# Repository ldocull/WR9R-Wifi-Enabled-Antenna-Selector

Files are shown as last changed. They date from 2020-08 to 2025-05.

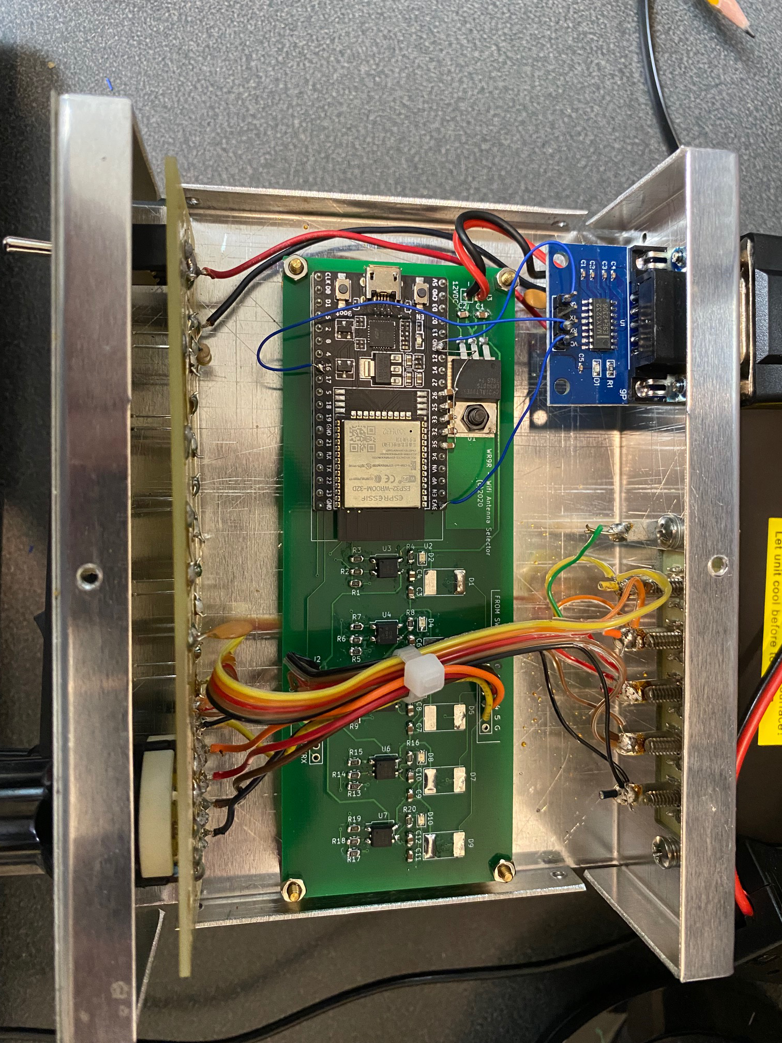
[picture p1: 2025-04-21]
RS232_Upgrade/Installed.jpg

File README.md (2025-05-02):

# WR9R-Wifi-Enabled-Antenna-Selector
This PCBA provides a method to remotely control antenna selection within a LAN using a standard browser.  I like to operate my HAM station, which is located in the basement, from other areas in or around my home.  This PCB and Firmware upgrade was easy to apply to my existing [Ameritron RCS-8V](https://mfjenterprises.com/products/rcs-8v) Antenna Selector control box while still maintaining manual control when I am in the basement radio-shack. 

## Key features:

- Directly fits within the existing enclosure
- Supports original manual control but adds remote control 
  (Changing the antenna choice at the front panel at any time, resets the device to the manual selection mode)
- Browser buttons can be named through the browser to support antenna upgrades

Typical Antenna Remote Controller Box

Installation

## Assembly Installation:

 The control wires were clipped from the back terminal strip and landed to the rear of the PCBA as shown above.
- New wires were the placed from the "To Relays" header to the terminal strip
- 12VDC power was picked up at the DC jack on the rear of the enclosure -- but could be picked up after the from panel switch on the front PCBA.

Main Operating Screen

## Setup:

 The software can be modified and hard coded to your network. Otherwise you can set it up using a phone or other internet-ready device. Connect to the Wifi hotspot generated by the Antenna Selector interface that looks like:  *WR9RasNNN*,  where *NNN* is a somewhat random number.
- Password is '*12345678*'
- On the same device, use a browser to then go to the host address:  https://192.168.4.1/SSID



- There, enter the SSID and Password for the network you wish to use within your LAN
- If you're plugged into the wifi module of the new PCBA with a USB cable, you can use a terminal session to see the new IP.  Otherwise. you will need to log into your router to find the new address assigned to the device.

## Antenna Names:
The buttons on the main screen can be renamed at any time. Just go to **htpps://*yourIPadd*/NAMES**



73
-[WR9R](http://wr9r.com/) 

___
Let us know that this work has been helpful to you.  Any proceeds will be used to offset expenses and further the art. 


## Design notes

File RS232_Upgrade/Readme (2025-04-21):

This upgrade allows the antenna selector to also directly monitor the K3.. allows for better responsiveness 
with band changes (does not have to rely on wifi). So, when running stuff like VarAC, no additional apps are requred for
monitoring and controlling the switch wirelessly. (Set the manual switch to position 5 to enable this function. 
Otherwise, everything is the same.)

73,
WR9R

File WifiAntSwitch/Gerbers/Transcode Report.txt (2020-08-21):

   ---- Transcoding 'C:\Users\LOCull.STRYKERCORP\Dropbox\KiCAD\WifiAntSwitch\Gerbers\WifiAntSwitch-Edge_Cuts.gbr' ----   Fri Aug 07 08:57:12 2020

D10   --> D100
-----------------------------------------------------------------

   ---- Transcoding 'C:\Users\LOCull.STRYKERCORP\Dropbox\KiCAD\WifiAntSwitch\Gerbers\WifiAntSwitch-F_Cu.gbr' ----   Fri Aug 07 08:57:12 2020

D17   --> D101
D18   --> D102
-----------------------------------------------------------------

   ---- Transcoding 'C:\Users\LOCull.STRYKERCORP\Dropbox\KiCAD\WifiAntSwitch\Gerbers\WifiAntSwitch-F_SilkS.gbr' ----   Fri Aug 07 08:57:12 2020

D10   --> D103
D11   --> D104
D12   --> D105
D13   --> D106
-----------------------------------------------------------------

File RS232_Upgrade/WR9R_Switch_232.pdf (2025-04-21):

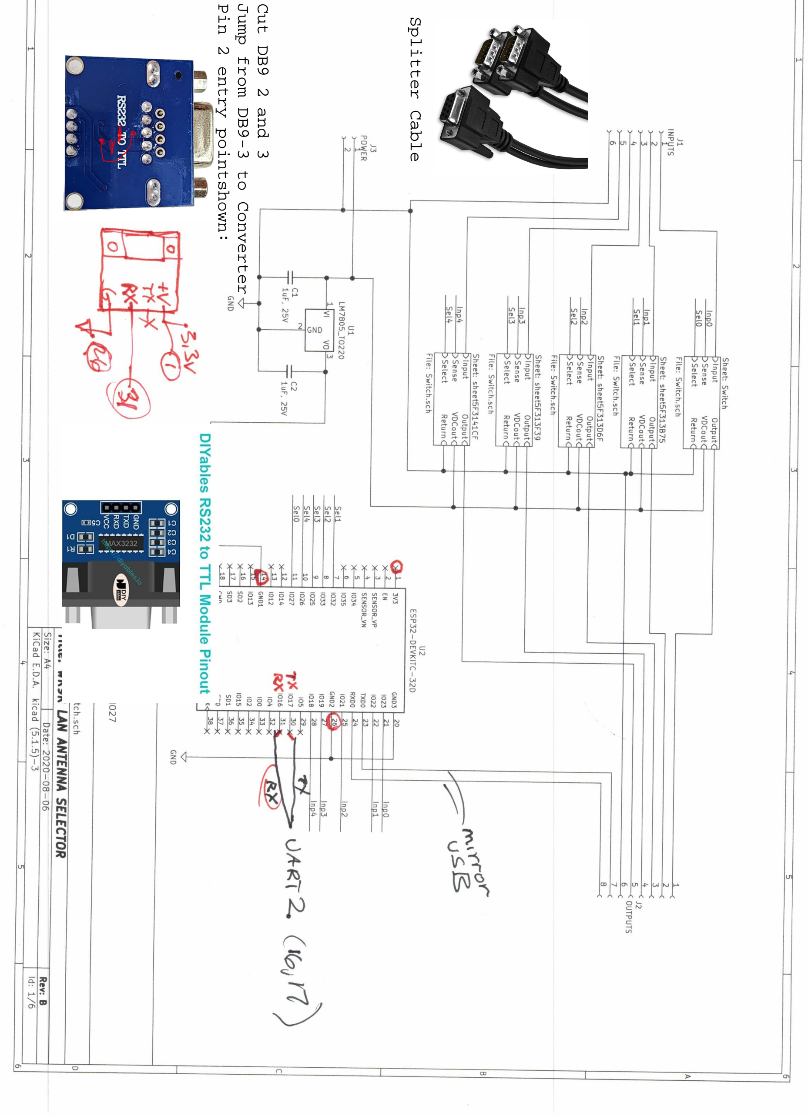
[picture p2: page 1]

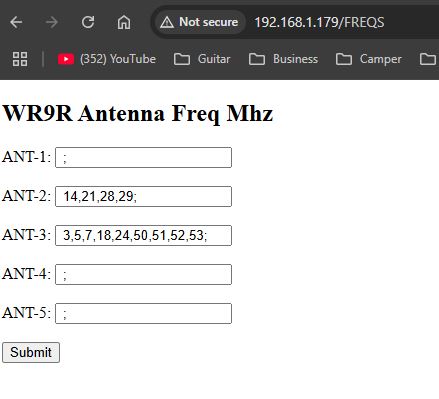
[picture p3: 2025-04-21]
RS232_Upgrade/FREQS_page_image.JPG

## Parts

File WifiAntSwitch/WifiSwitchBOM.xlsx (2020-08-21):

Id | Designator | Package | Quantity | Designation | Supplier and ref | Column1 | _1
1 | U2 | MODULE_ESP32-DEVKITC-32D | 1 | ESP32-DEVKITC-32D | 356-ESP32-DEVKITC32D (https://www.mouser.com/ProductDetail/356-ESP32-DEVKITC32D)
4 | U1 | TO-220-3_Horizontal_TabDown | 1 | LM7805_TO220 | LM7805CT/NOPB (https://www.mouser.com/ProductDetail/Texas-Instruments/LM7805CT-NOPB?qs=OYMYEaN9QmBS2GvaX6GSkQ%3D%3D)
5 | D9,D7,D5,D3,D1 | D_3220_8050Metric | 5 | RS07D-HM3-08 | RS07D-HM3-08
6 | U7,U6,U5,U4,U3 | SO-4_4.4x4.3mm_P2.54mm | 5 | ASSR-1218 | ASSR-1218-003E (https://www.mouser.com/ProductDetail/Broadcom-Avago/ASSR-1218-003E?qs=qH0Js2SSo34eOC1tecF2yQ%3D%3D)
7 | R20,R18,R16,R14,R12,R10,R8,R6,R4,R2 | R_0805_2012Metric | 10 | 6.8K | CR0805-FX-6801ELF (https://www.mouser.com/ProductDetail/Bourns/CR0805-FX-6801ELF)
8 | R19,R15,R11,R7,R3 | R_0805_2012Metric | 5 | 510 | CR0805-FX-5100ELF
9 | R17,R13,R9,R5,R1 | R_0805_2012Metric | 5 | 22K | CR0805-FX-2202ELF
12 | D10,D8,D6,D4,D2 | LED_0805_2012Metric | 5 | 599-0120-007F | 599-0120-007F (https://www.mouser.com/ProductDetail/Dialight/599-0120-007F?qs=gTYE2QTfZfSQtH19g4L1Mg%3D%3D)
13 | C12,C10,C8,C6,C4 | C_0805_2012Metric | 5 | 0.01uf, 100V | HMF212B7103KGHT (https://www.mouser.com/ProductDetail/Taiyo-Yuden/HMF212B7103KGHT)
14 | C11,C9,C7,C5,C3,C2,C1 | C_0805_2012Metric | 7 | 1uF, 25V | 08053G105MAT2A (https://www.mouser.com/ProductDetail/AVX/08053G105MAT2A)

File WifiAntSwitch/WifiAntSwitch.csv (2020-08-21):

Id | Designator | Package | Quantity | Designation | Supplier and ref
1 | U2 | MODULE_ESP32-DEVKITC-32D | 1 | ESP32-DEVKITC-32D
2 | J3 | PinHeader_1x02_P2.54mm_Vertical | 1 | POWER
3 | REF**,REF**,REF**,REF** | MountingHole_3mm | 4 | MountingHole_3mm
4 | U1 | TO-220-3_Horizontal_TabDown | 1 | LM7805_TO220
5 | D9,D7,D5,D3,D1 | D_3220_8050Metric | 5 | RS07D-HM3-08
6 | U7,U6,U5,U4,U3 | SO-4_4.4x4.3mm_P2.54mm | 5 | ASSR-1218
7 | R20,R18,R16,R14,R12,R10,R8,R6,R4,R2 | R_0805_2012Metric | 10 | 6.8K
8 | R19,R15,R11,R7,R3 | R_0805_2012Metric | 5 | 510
9 | R17,R13,R9,R5,R1 | R_0805_2012Metric | 5 | 22K
10 | J2 | PinHeader_1x08_P2.54mm_Vertical | 1 | OUTPUTS
11 | J1 | PinHeader_1x06_P2.54mm_Vertical | 1 | INPUTS
12 | D10,D8,D6,D4,D2 | LED_0805_2012Metric | 5 | 599-0120-007F
13 | C12,C10,C8,C6,C4 | C_0805_2012Metric | 5 | 0.01uf, 100V
14 | C11,C9,C7,C5,C3,C2,C1 | C_0805_2012Metric | 7 | 1uF, 25V

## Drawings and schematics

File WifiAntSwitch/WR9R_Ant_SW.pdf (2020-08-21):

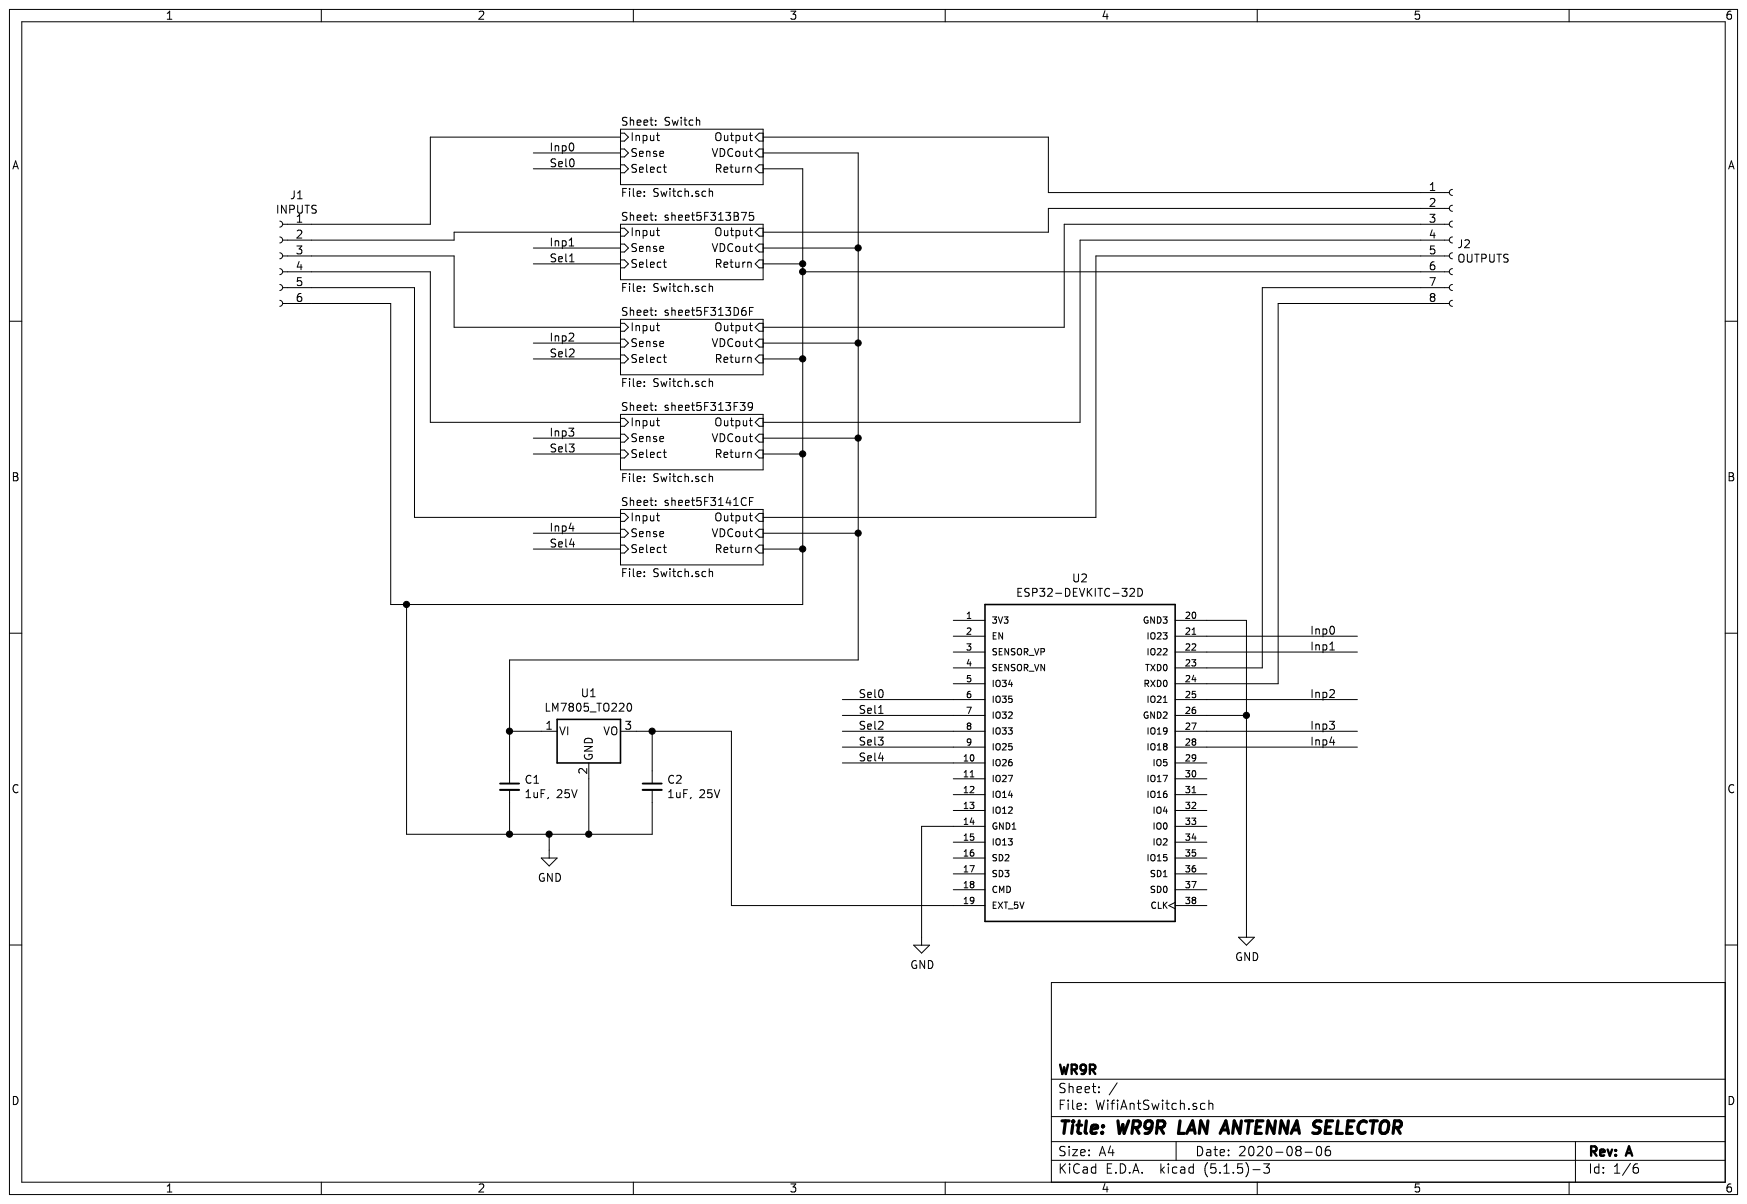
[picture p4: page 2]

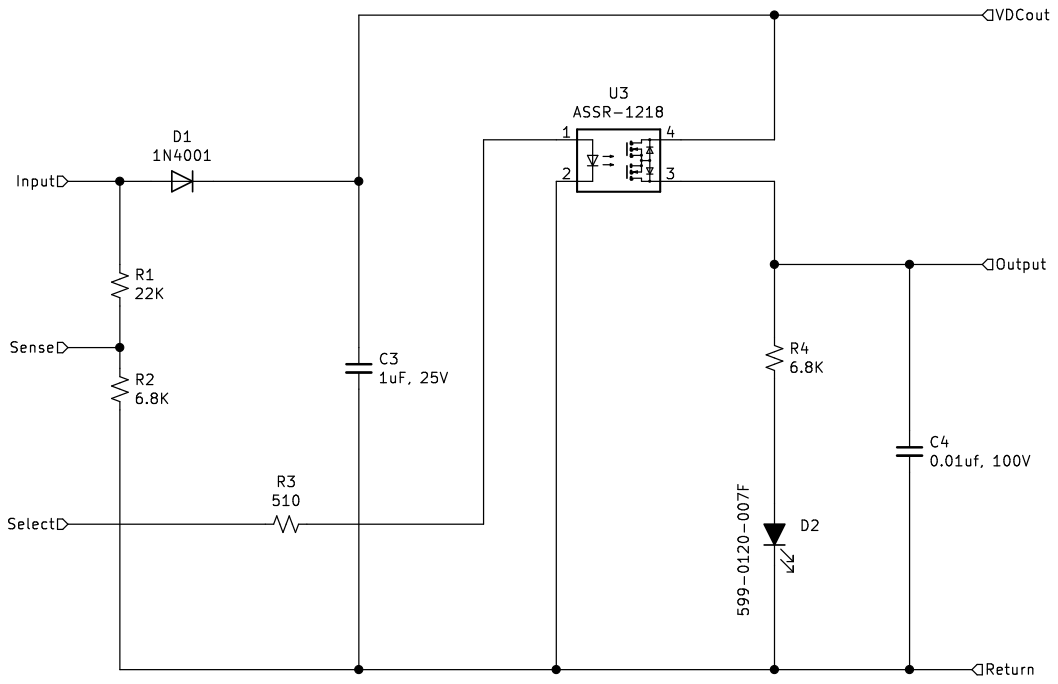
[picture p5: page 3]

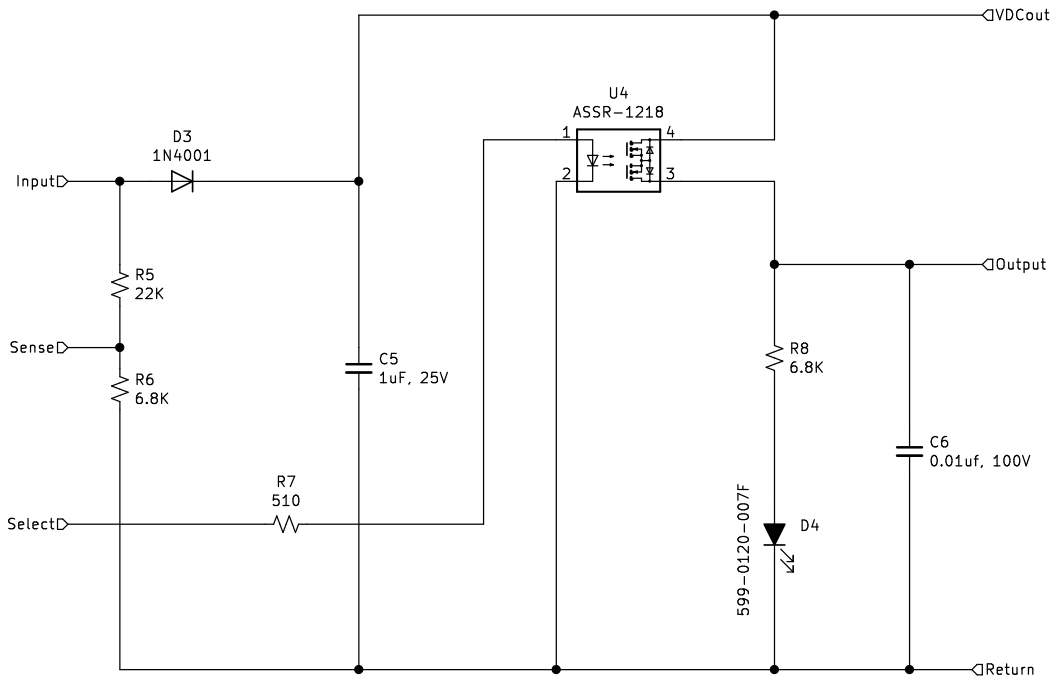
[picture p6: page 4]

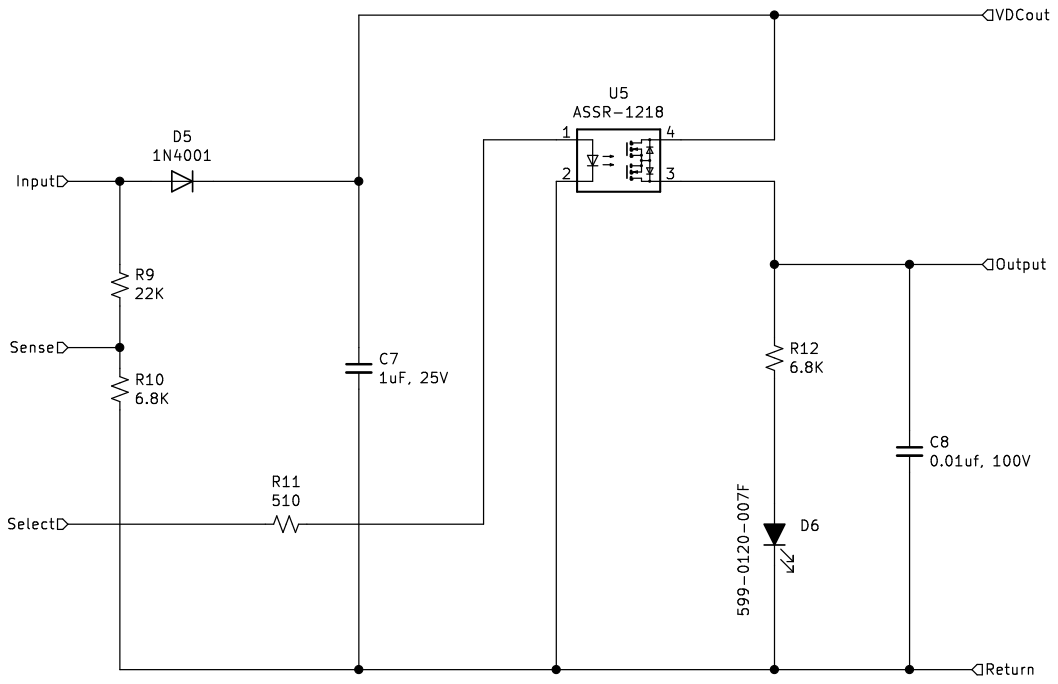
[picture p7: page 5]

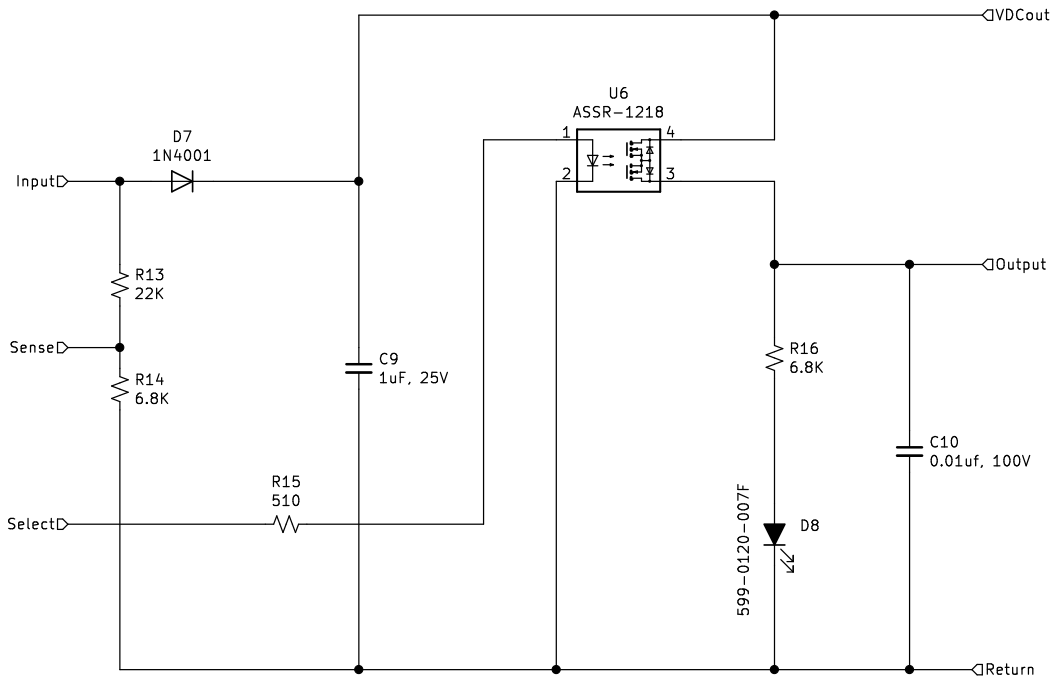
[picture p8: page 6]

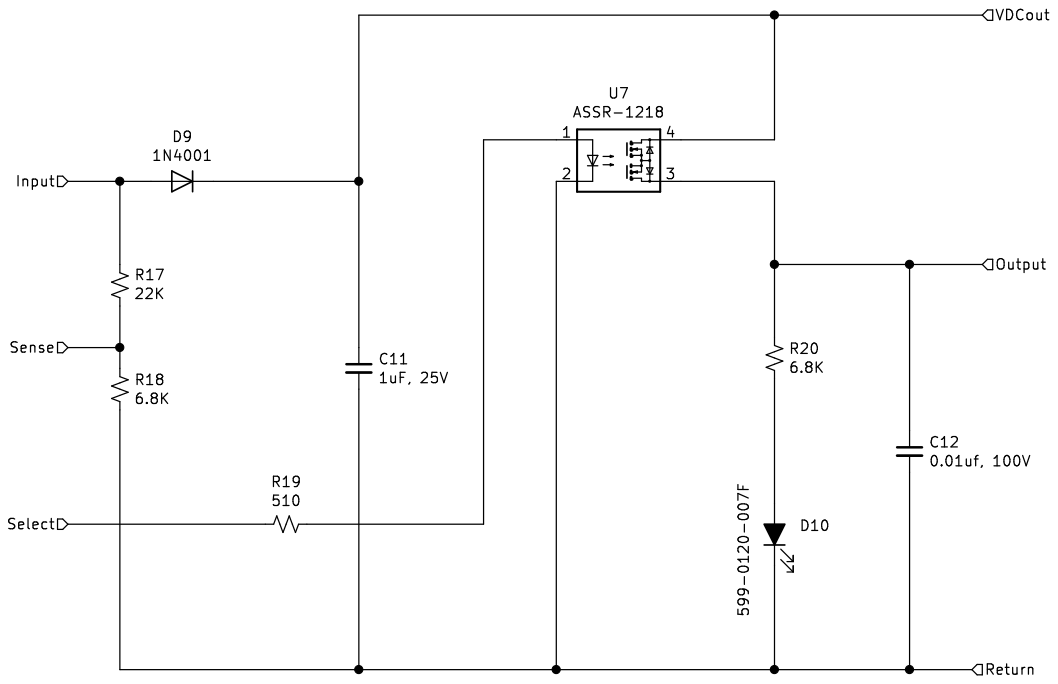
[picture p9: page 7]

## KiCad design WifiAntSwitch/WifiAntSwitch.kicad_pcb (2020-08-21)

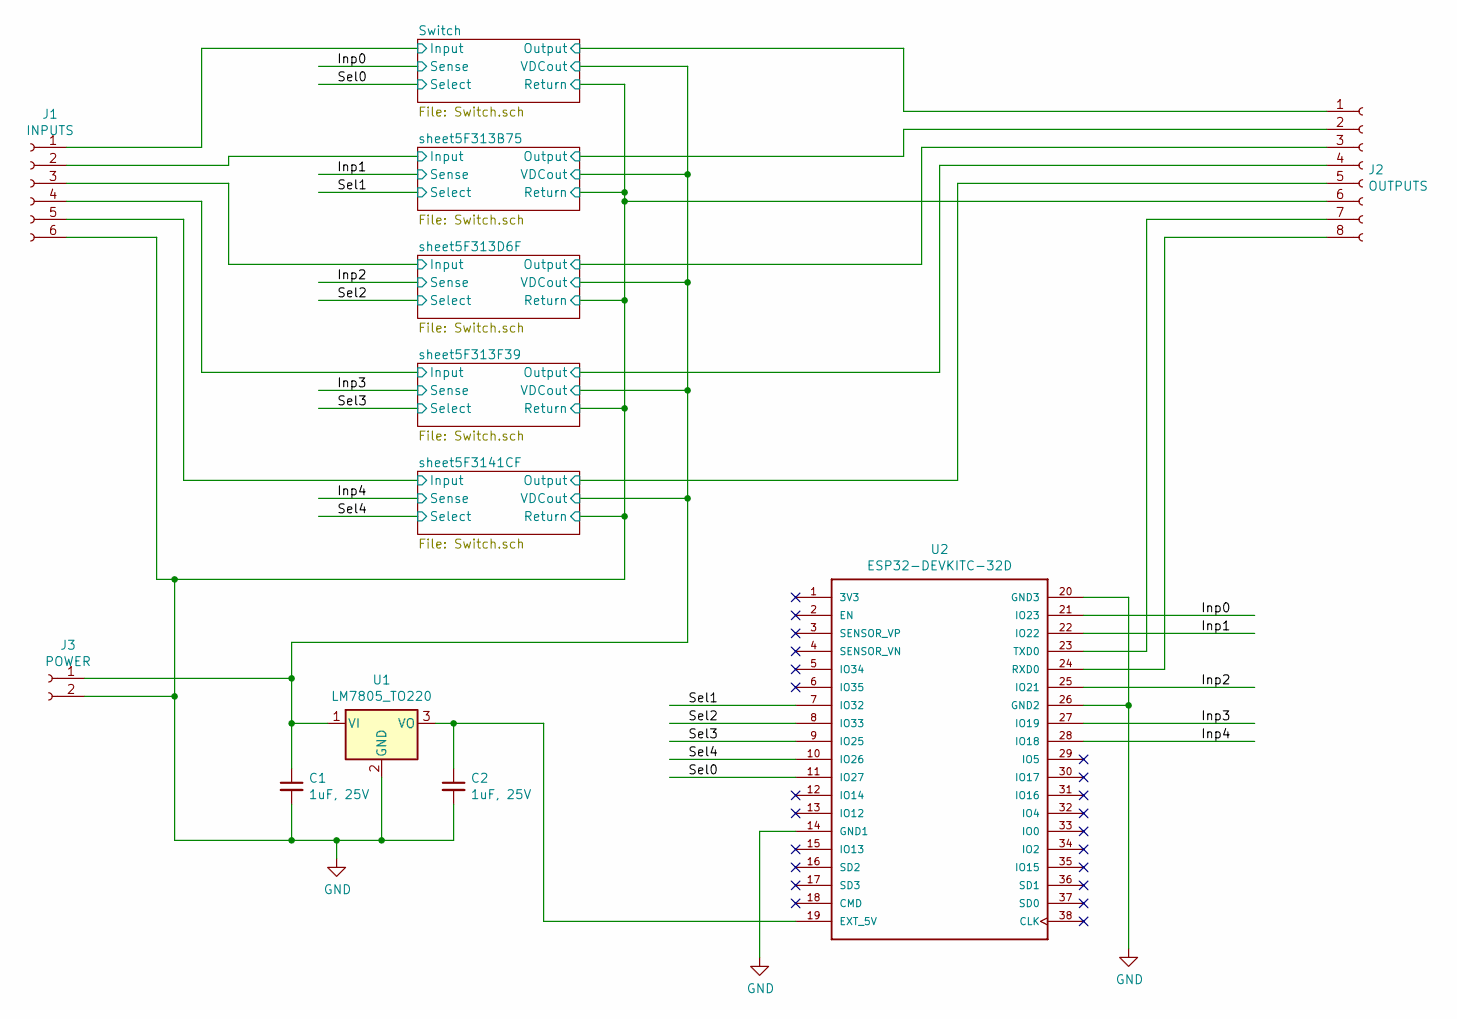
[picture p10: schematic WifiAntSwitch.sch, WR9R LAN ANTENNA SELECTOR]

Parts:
C1, C2: 1uF, 25V; C_0805_2012Metric
J1: INPUTS; PinHeader_1x06_P2.54mm_Vertical
J2: OUTPUTS; PinHeader_1x08_P2.54mm_Vertical
J3: POWER; PinHeader_1x02_P2.54mm_Vertical
U1: LM7805_TO220; TO-220-3_Horizontal_TabDown
U2: ESP32-DEVKITC-32D; MODULE_ESP32-DEVKITC-32D

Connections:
/Inp0: U2.21 (IO23); also elsewhere on the board
/Inp1: U2.22 (IO22); also elsewhere on the board
/Inp2: U2.25 (IO21); also elsewhere on the board
/Inp3: U2.27 (IO19); also elsewhere on the board
/Inp4: U2.28 (IO18); also elsewhere on the board
/Sel0: U2.11 (IO27); also elsewhere on the board
/Sel1: U2.7 (IO32); also elsewhere on the board
/Sel2: U2.8 (IO33); also elsewhere on the board
/Sel3: U2.9 (IO25); also elsewhere on the board
/Sel4: U2.10 (IO26); also elsewhere on the board
/Switch/Input: J1.1; also elsewhere on the board
/Switch/Output: J2.1; also elsewhere on the board
/Switch/VDCout: C1.1, J3.1, U1.1 (VI); also elsewhere on the board
/sheet5F313B75/Input: J1.2; also elsewhere on the board
/sheet5F313B75/Output: J2.2; also elsewhere on the board
/sheet5F313D6F/Input: J1.3; also elsewhere on the board
/sheet5F313D6F/Output: J2.3; also elsewhere on the board
/sheet5F313F39/Input: J1.4; also elsewhere on the board
/sheet5F313F39/Output: J2.4; also elsewhere on the board
/sheet5F3141CF/Input: J1.5; also elsewhere on the board
/sheet5F3141CF/Output: J2.5; also elsewhere on the board
GND: C1.2, C2.2, J1.6, J2.6, J3.2, U1.2 (GND), U2.14 (GND1), U2.20 (GND3), U2.26 (GND2); also elsewhere on the board
unnamed: C2.1, U1.3 (VO), U2.19 (EXT_5V)
unnamed: J2.7, U2.23 (TXD0)
unnamed: J2.8, U2.24 (RXD0)

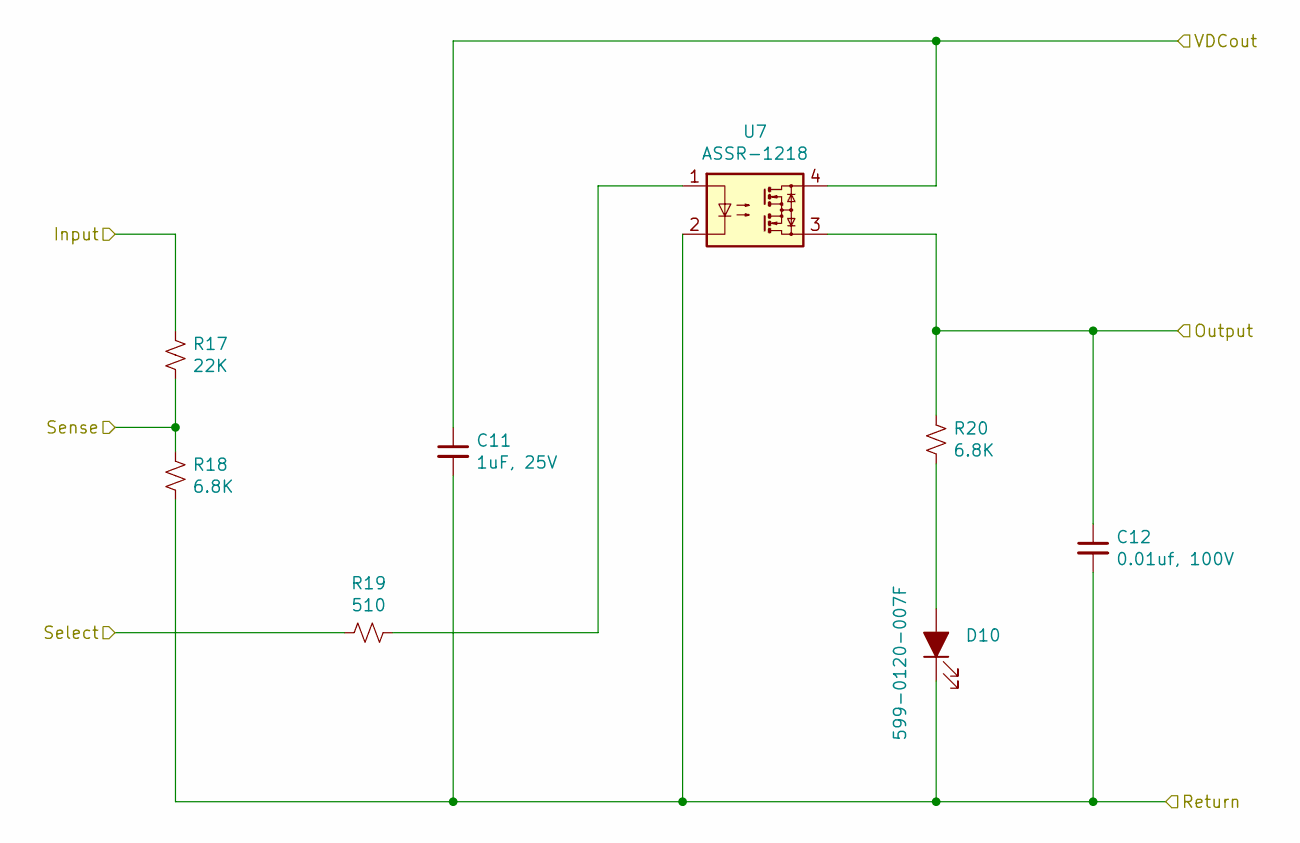
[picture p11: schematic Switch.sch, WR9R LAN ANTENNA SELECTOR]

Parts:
C3: 1uF, 25V; C_0805_2012Metric
C4: 0.01uf, 100V; C_0805_2012Metric
D10: 599-0120-007F; LED_0805_2012Metric
R1: 22K; R_0805_2012Metric
R2, R4: 6.8K; R_0805_2012Metric
R3: 510; R_0805_2012Metric
U3: ASSR-1218; SO-4_4.4x4.3mm_P2.54mm

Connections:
/Inp0: R1.1, R2.1; also elsewhere on the board
/Sel0: R3.2; also elsewhere on the board
/Switch/Input: R1.2; also elsewhere on the board
/Switch/Output: C4.1, R4.1, U3.3; also elsewhere on the board
/Switch/VDCout: C3.1, U3.4; also elsewhere on the board
GND: C3.2, C4.2, D10.1 (K), R2.2, U3.2; also elsewhere on the board
unnamed: R3.1, U3.1

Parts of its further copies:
C5, C7, C9, C11: 1uF, 25V; C_0805_2012Metric
C6, C8, C10, C12: 0.01uf, 100V; C_0805_2012Metric
D2, D4, D6, D8: 599-0120-007F; LED_0805_2012Metric
R5, R9, R13, R17: 22K; R_0805_2012Metric
R6, R8, R10, R12, R14, R16, R18, R20: 6.8K; R_0805_2012Metric
R7, R11, R15, R19: 510; R_0805_2012Metric
U4, U5, U6, U7: ASSR-1218; SO-4_4.4x4.3mm_P2.54mm

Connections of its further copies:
/Inp1: R5.1, R6.1; also elsewhere on the board
/Inp2: R9.1, R10.1; also elsewhere on the board
/Inp3: R13.1, R14.1; also elsewhere on the board
/Inp4: R17.1, R18.1; also elsewhere on the board
/Sel1: R7.2; also elsewhere on the board
/Sel2: R11.2; also elsewhere on the board
/Sel3: R15.2; also elsewhere on the board
/Sel4: R19.2; also elsewhere on the board
/Switch/VDCout: C5.1, C7.1, C9.1, C11.1, U4.4, U5.4, U6.4, U7.4; also elsewhere on the board
/sheet5F313B75/Input: R5.2; also elsewhere on the board
/sheet5F313B75/Output: C6.1, R8.1, U4.3; also elsewhere on the board
/sheet5F313D6F/Input: R9.2; also elsewhere on the board
/sheet5F313D6F/Output: C8.1, R12.1, U5.3; also elsewhere on the board
/sheet5F313F39/Input: R13.2; also elsewhere on the board
/sheet5F313F39/Output: C10.1, R16.1, U6.3; also elsewhere on the board
/sheet5F3141CF/Input: R17.2; also elsewhere on the board
/sheet5F3141CF/Output: C12.1, R20.1, U7.3; also elsewhere on the board
GND: C5.2, C6.2, C7.2, C8.2, C9.2, C10.2, C11.2, C12.2, D2.1 (K), D4.1 (K), D6.1 (K), D8.1 (K), R6.2, R10.2, R14.2, R18.2, U4.2, U5.2, U6.2, U7.2; also elsewhere on the board
unnamed: D4.2 (A), R8.2
unnamed: D6.2 (A), R12.2
unnamed: D8.2 (A), R16.2
unnamed: R7.1, U4.1
unnamed: R11.1, U5.1
unnamed: R15.1, U6.1
unnamed: R19.1, U7.1

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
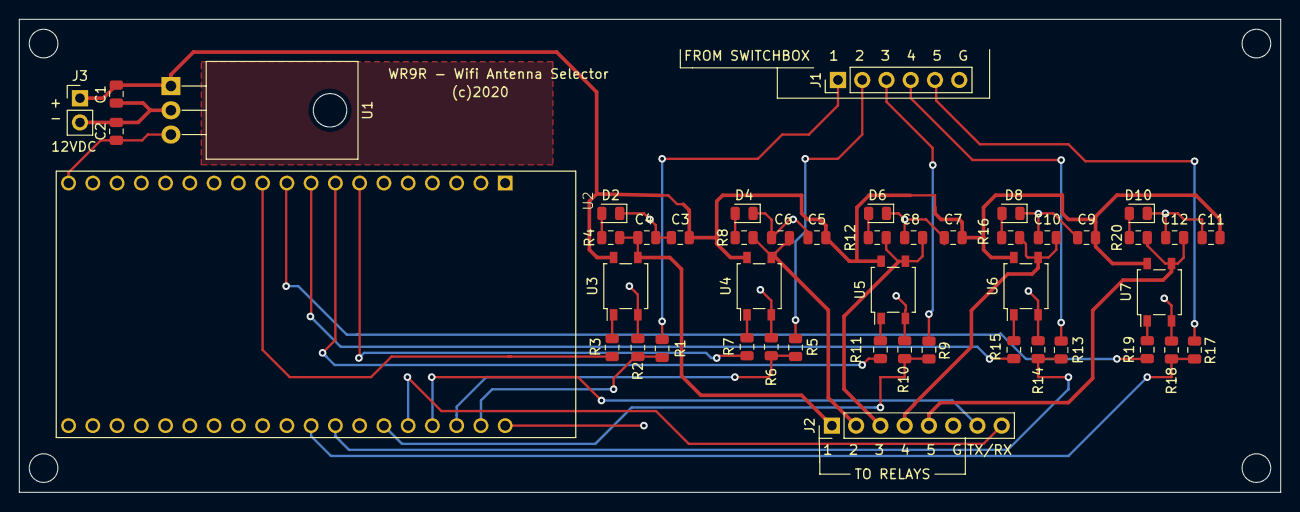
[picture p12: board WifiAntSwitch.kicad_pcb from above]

Board: 2 copper layers, 132.1 x 49.5 mm, 47 parts (0 on the bottom side), 35 nets.

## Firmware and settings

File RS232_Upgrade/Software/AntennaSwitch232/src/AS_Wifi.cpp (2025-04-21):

/*
    WR9R Antenna Switch Wifi server firmware..
    this package runs native on ESP32 and provides the web
    interface for the WR9R Antenna Selector Server product.
   
    Aug 2020
    -Larry D O'Cull  WR9R  (c)2020

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
 * THE SOFTWARE IS PROVIDED "AS IS", WITHOUT WARRANTY OF ANY KIND, EXPRESS OR
 * IMPLIED, INCLUDING BUT NOT LIMITED TO THE WARRANTIES OF MERCHANTABILITY, FITNESS
 * FOR A PARTICULAR PURPOSE AND NONINFRINGEMENT. IN NO EVENT SHALL THE AUTHORS OR
 * COPYRIGHT HOLDERS BE LIABLE FOR ANY CLAIM, DAMAGES OR OTHER LIABILITY, WHETHER
 * IN AN ACTION OF CONTRACT, TORT OR OTHERWISE, ARISING FROM, OUT OF OR IN
 * CONNECTION WITH THE SOFTWARE OR THE USE OR OTHER DEALINGS IN THE SOFTWARE.    
*/

#include "AS_Wifi.h"

//
// EEPROM mapping for stored params (Names, SSID, etc.)
//
#define TAG_INIT_0 0xBB
#define TAG_INIT_1 0xAA
#define TAG_ADDRESS 0
char tag[2];
#define SSID_ADDRESS 4
char ssid[64];
#define PSWD_ADDRESS (24+4)
char password[64];
#define ANT_NAME_ADDRESS (24+4+64+4)
#define ANT_ADDR_OFFSET 64
char antennaName[6][ANT_ADDR_OFFSET];
#define ANT_FREQ_ADDRESS (ANT_NAME_ADDRESS+(6*(ANT_ADDR_OFFSET)))
char antennaFreq[6][ANT_ADDR_OFFSET];
#define EEPROM_SIZE (ANT_FREQ_ADDRESS+(6*ANT_ADDR_OFFSET))

char myIPstr[40];
String myIPstring;
WebServer server(80);

volatile int interruptCounter;
int totalInterruptCounter;


int switchStatus = 0;
int lastSwitchStatus = 0;

/* 
    Direct radio monitoring add on for Elecraft K3, Kenwood, etc.
    Apl 19, 2025   LDO

  Comms look like this --->   ;FA00005355170; 
    FA000xx******;
    where xx is megahertz
 if selector is in the SW1 (switchStatus = 16) position -- no changes
 if selector is in the SW5 (switchStatus = 1) position -- then auto changes
 so SW2,S3 not assigned
         SW1  10;                               --- multiband vertical here (30M)
         SW2  14,21,28,29;                      --- Beam is setup here (20,15,10M)
         SW3  03,05,07,18,24,50,51,52,53;       --- multiband dipole here (80,60,40,17,12,6M)
         SW4  ;
         SW5  ;
*/

#define NUM_BANDS 5
#define MAX_VALUES_PER_BAND 16
char band_inputs[200];
int bands[NUM_BANDS][MAX_VALUES_PER_BAND];
int band_lengths[NUM_BANDS];

int parse_band(const char *s, int *arr, int max_elements) {
    int count = 0;
    const char *ptr = s;

    while (*ptr != '\0' && *ptr != ';' && count < max_elements) {
        arr[count++] = strtol(ptr, (char**)&ptr, 10);
        while (*ptr == ',') ptr++;
    }

    return count;
}

int parse_bands(const char *s, int bands[NUM_BANDS][MAX_VALUES_PER_BAND], int *band_lengths) {
    int band = 0;
    const char *ptr = s;

    while (*ptr != '\0' && band < NUM_BANDS) {
        const char *end = strchr(ptr, ';');
        char temp[128];

        if (end) {
            size_t len = end - ptr;
            strncpy(temp, ptr, len);
            temp[len] = '\0';
            ptr = end + 1;
        } else {
            strcpy(temp, ptr);
            ptr += strlen(ptr);
        }

        band_lengths[band] = parse_band(temp, bands[band], MAX_VALUES_PER_BAND);
        band++;
    }

    return band; // Number of bands parsed
}

void setupBandPlan()
{
  int i = 0;
  band_inputs[0] = 0;
  for(i=0; i<NUM_BANDS; i++)
  {
      strcat(band_inputs, antennaFreq[i]); // retrieve freqs for each band
  }
  DEBUG_PORT.printf("INPUT:%s\n", band_inputs);

  parse_bands(band_inputs, bands, band_lengths);

  for (i = 0; i < NUM_BANDS; i++) {
      DEBUG_PORT.printf("Band %d: %d -", i, band_lengths[i]);
      for (int j = 0; j < band_lengths[i]; j++) {
          DEBUG_PORT.printf("%d ", bands[i][j]);
      }
      DEBUG_PORT.printf("\n");
  }
}

int find_band_for_frequency(int megaHZ) {
  for (int i = 0; i < NUM_BANDS; i++) {
      for (int j = 0; j < band_lengths[i]; j++) {
          if (bands[i][j] == megaHZ) {
              return i; // Found the band
          }
      }
  }
  return -1; // Not found
}

/*
  poll for the passing rig traffic and grab the megahertz to determine which antenna is required
  based on the table programmed into the FREQ table via the web settings
  Comms look like this --->   ;FA00005355170; 
    FA000xx******;
    where xx is megahertz
*/
int band_index = 9, last_band_index = -1;

int poll_radio_for_frequency() {
    static char buffer[64];
    static int index = 0;

    while (RADIO_PORT.available()) {
        char c = RADIO_PORT.read();
    // while (DEBUG_PORT.available()) {
    //   char c = DEBUG_PORT.read();

        // Start a new message if 'F' is seen
        if (c == 'F') {
            index = 0;
        }

        // Store the character if there's room
        if (index < sizeof(buffer) - 1) {
            buffer[index++] = c;
            buffer[index] = '\0'; // null-terminate
        } else {
            // If buffer overflows, reset
            index = 0;
        }

        // Check for complete message once ';' is seen
        if (c == ';' && index == 14) {
            // Message should be exactly 14 characters: "FA000mmdddddd;"
            if (strncmp(buffer, "FA000", 5) == 0) {
                char mhz_str[3] = { buffer[5], buffer[6], '\0' };
                int megaHZ = atoi(mhz_str);
                index = 0; // Reset for next message
                return megaHZ;
            } else {
                // Invalid message, reset buffer
                index = 0;
            }
        }
    }

    return 0; // No complete message yet
}

void read_Radio()
{ 
                                  // otherwise follow the web or front panel
  int megaHZ = poll_radio_for_frequency();

  if(switchStatus != 1)
  {
    last_band_index = -1;
    return;   // require the switch in this position for "direct AUTO"
  }

  if(megaHZ > 0)     // nothing to see here if 0
  {
    band_index = find_band_for_frequency(megaHZ);
    if (band_index != -1) {
      DEBUG_PORT.printf("Frequency %d MHz found in band %d\n", megaHZ, band_index);

      if(band_index != last_band_index) // is this a new frequency band ?
      {
        Output_Change((band_index)+1); // if so, set switch accordingly
        last_band_index = band_index;
      }
      else 
        DEBUG_PORT.printf("no change\n");
    } 
    else 
    {
      DEBUG_PORT.printf("Frequency %d MHz not found in any band\n", megaHZ);
    }
  }
}

hw_timer_t * timer = NULL;
portMUX_TYPE timerMux = portMUX_INITIALIZER_UNLOCKED;
 
void IRAM_ATTR onTimer() {
  portENTER_CRITICAL_ISR(&timerMux);
  interruptCounter++;
  portEXIT_CRITICAL_ISR(&timerMux);
 
}

// Current time
unsigned long currentTime = millis();
// Previous time
unsigned long previousTime = 0; 
// Define timeout time in milliseconds (example: 2000ms = 2s)
const long timeoutTime = 2000;

//
// String clean up routines
//
char *ltrim(char *s)  // left trim of spaces..
{
    char *start;

    start = s;
    while(isspace(*s))
          s++;
    strcpy(start,s);

    return start;
}

char *rtrim(char *s)  // right trim of spaces
{
    char* back = s + strlen(s);
    while(isspace(*--back));
    *(back+1) = '\0';

    return s;
}

char *trim(char *s)   // trim ends of spaces..
{
    return rtrim(ltrim(s)); 
}

//
// Save EEPROM string parameters
//
void EEStore(int addr, char *cptr)
{
    int i = 0;

    while(*cptr != 0)      // put a string in EEPROM
    {
      EEPROM.write(addr++, *cptr);
      cptr++;
      if(++i > 63) return;  // prevent damage...
    }
    EEPROM.write(addr, 0); // end the string..
}

//
// Restrore EEPROM string parameters
//
void EERecover(int addr, char *cptr)
{
    do  // recover a string from EEPROM
    {
      *cptr = EEPROM.read(addr++);
    } while (*cptr++ != 0);
    
}

//
// Save a list of settings and commit to EEPROM
//
void saveSettings()
{
        EEStore(SSID_ADDRESS, ssid);
        EEStore(PSWD_ADDRESS, password);

        for(int i=0; i<5; i++)
        {
            EEStore(ANT_NAME_ADDRESS + (ANT_ADDR_OFFSET * (i)), trim(antennaName[i]));
        }

        for(int i=0; i<5; i++)
        {
            EEStore(ANT_FREQ_ADDRESS + (ANT_ADDR_OFFSET * (i)), trim(antennaFreq[i]));
        }

        EEPROM.write(TAG_ADDRESS, TAG_INIT_0);  // tag to show the EEPROM initialized and valid
        EEPROM.write(TAG_ADDRESS+1, TAG_INIT_1);

        EEPROM.commit();
}

//
// recover stored antenna descriptor names if available
//
String antName[6];  // antenna descriptor - name
void getNames()
{
        for(int i=0; i<5; i++)
        {
            EERecover(ANT_NAME_ADDRESS + (ANT_ADDR_OFFSET * (i)), antennaName[i]);
            antName[i] = (String)(trim(antennaName[i]));
        }
}

//
// recover stored antenna freq lists (strings) if available
//
String antFreq[6];  // antenna descriptor - name
void getFreqs()
{ 
        for(int i=0; i<5; i++)
        {
            EERecover(ANT_FREQ_ADDRESS + (ANT_ADDR_OFFSET * (i)), antennaFreq[i]);
            antFreq[i] = (String)(trim(antennaFreq[i]));
            DEBUG_PORT.printf("[%s]\n",trim(antennaFreq[i])); // list what I have to work with,,,
        }
}

//
//  Set names of buttons to antenna descriptors
//
void NAMEchange()
{
  String tempStr;

  if (server.hasArg("ant1") || server.hasArg("ant2") ||
        server.hasArg("ant3") || server.hasArg("ant4") ||
          server.hasArg("ant5"))
  {
      antName[0] = server.arg("ant1");    // new assignments to names...
      antName[1] = server.arg("ant2");
      antName[2] = server.arg("ant3");
      antName[3] = server.arg("ant4");
      antName[4] = server.arg("ant5");

      for(int x=0; x<5; x++)
      {
        strcpy(antennaName[x], antName[x].c_str()); // prep to store in EEPROM
        trim(antennaName[x]);
        antName[x] = (String)antennaName[x];
      }
      saveSettings();
  }
  tempStr = NAMESformhtml;
  tempStr += "<label for=\"ant1\">ANT-1: </label><input type=\"text\" id=\"ant1\" value=\" " + antName[0] + "\" name=\"ant1\"><br><br>";
  tempStr += "<label for=\"ant2\">ANT-2: </label><input type=\"text\" id=\"ant2\" value=\" " + antName[1] + "\" name=\"ant2\"><br><br>";
  tempStr += "<label for=\"ant3\">ANT-3: </label><input type=\"text\" id=\"ant3\" value=\" " + antName[2] + "\"  name=\"ant3\"><br><br>";
  tempStr += "<label for=\"ant4\">ANT-4: </label><input type=\"text\" id=\"ant4\" value=\" " + antName[3] + "\"  name=\"ant4\"><br><br>";
  tempStr += "<label for=\"ant5\">ANT-5: </label><input type=\"text\" id=\"ant5\" value=\" " + antName[4] + "\"  name=\"ant5\"><br><br>";
  tempStr += NAMESendhtml;
  server.send(200, "text/html", tempStr);
}

//
//  Set Frequencies of antenna descriptors
//
void FREQchange()
{
  String tempStr;

  if (server.hasArg("ant1") || server.hasArg("ant2") ||
        server.hasArg("ant3") || server.hasArg("ant4") ||
          server.hasArg("ant5"))
  {
      antFreq[0] = server.arg("ant1");    // new assignments to Freqs...
      antFreq[1] = server.arg("ant2");
      antFreq[2] = server.arg("ant3");
      antFreq[3] = server.arg("ant4");
      antFreq[4] = server.arg("ant5");

      for(int x=0; x<5; x++)
      {
        strcpy(antennaFreq[x], antFreq[x].c_str()); // prep to store in EEPROM
        trim(antennaFreq[x]);
        antFreq[x] = (String)antennaFreq[x];
      }
      saveSettings();
  }
  tempStr = FREQSformhtml;
  tempStr += "<label for=\"ant1\">ANT-1: </label><input type=\"text\" id=\"ant1\" value=\" " + antFreq[0] + "\" name=\"ant1\"><br><br>";
  tempStr += "<label for=\"ant2\">ANT-2: </label><input type=\"text\" id=\"ant2\" value=\" " + antFreq[1] + "\" name=\"ant2\"><br><br>";
  tempStr += "<label for=\"ant3\">ANT-3: </label><input type=\"text\" id=\"ant3\" value=\" " + antFreq[2] + "\"  name=\"ant3\"><br><br>";
  tempStr += "<label for=\"ant4\">ANT-4: </label><input type=\"text\" id=\"ant4\" value=\" " + antFreq[3] + "\"  name=\"ant4\"><br><br>";
  tempStr += "<label for=\"ant5\">ANT-5: </label><input type=\"text\" id=\"ant5\" value=\" " + antFreq[4] + "\"  name=\"ant5\"><br><br>";
  tempStr += FREQSendhtml;
  server.send(200, "text/html", tempStr);
}

//
// base website served up...
//
void handleRoot() {
  
  String output;

  digitalWrite(led, 1);
  
  output = AntennaSiteHeader;
  
  // output the stat of each antenna selector 
    output += ButtonHeader;
    if (digitalRead(output1))   // reflect output state graphically
    {
      output += "active_state";
    }
    else
    {
      output += "inactive_state";
    }
    output += "\" href=\"ONE\""; 
    output += ButtonBody;
    output += antName[0];
    output += ButtonFooter;

  // output the stat of each antenna selector 
    output += ButtonHeader;
    if (digitalRead(output2)) 
    {
      output += "active_state";
    }
    else
    {
      output += "inactive_state";
    }
    output += "\" href=\"TWO\""; 
    output += ButtonBody;
    output += antName[1];
    output += ButtonFooter;

  // output the stat of each antenna selector 
    output += ButtonHeader;
    if (digitalRead(output3)) 
    {
      output += "active_state";
    }
    else
    {
      output += "inactive_state";
    }
    output += "\" href=\"THREE\""; 
    output += ButtonBody;
    output += antName[2];
    output += ButtonFooter;

  // output the stat of each antenna selector 
    output += ButtonHeader;
    if (digitalRead(output4)) 
    {
      output += "active_state";
    }
    else
    {
      output += "inactive_state";
    }
    output += "\" href=\"FOUR\""; 
    output += ButtonBody;
    output += antName[3];
    output += ButtonFooter;

  // output the stat of each antenna selector 
    output += ButtonHeader;
    if (digitalRead(output5)) 
    {
      output += "active_state";
    }
    else
    {
      output += "inactive_state";
    }
    output += "\" href=\"FIVE\""; 
    output += ButtonBody;
    output += antName[4];
    output += ButtonFooter;

  output += AntennaFooter;

  server.send(200, "text/html", output);
  
  digitalWrite(led, 0);
}


//
//  Change output states from button post
//
void Output_Change(int i)
{ 
  String output;

  digitalWrite(led, 1);
  
  output = AntennaSiteHeader;
  
  // output the stat of each antenna selector 
    output += ButtonHeader;

    digitalWrite(output1,LOW);
    digitalWrite(output2,LOW);
    digitalWrite(output3,LOW);
    digitalWrite(output4,LOW);
    digitalWrite(output5,LOW);        // Change over antenna output relays... BREAK B4 MAKE
    
    switch (i)  
    {
        case 1:
          digitalWrite(output1,HIGH);
          DEBUG_PORT.println("Antenna 1..");
          break;

        case 2:
          digitalWrite(output2,HIGH);
          DEBUG_PORT.println("Antenna 2..");
          break;

        case 3:
          digitalWrite(output3,HIGH);
          DEBUG_PORT.println("Antenna 3..");
          break;

        case 4:
          digitalWrite(output4,HIGH);
          DEBUG_PORT.println("Antenna 4..");
          break;

        case 5:
          digitalWrite(output5,HIGH);
          DEBUG_PORT.println("Antenna 5..");
          break;
    }
      
    handleRoot();

}

void Output_Change_ONE()
{
  Output_Change(1);
}
void Output_Change_TWO()
{
  Output_Change(2);
}
void Output_Change_THREE()
{
  Output_Change(3);
}
void Output_Change_FOUR()
{
  Output_Change(4);
}
void Output_Change_FIVE()
{
  Output_Change(5);
}

//
// Change host network paramters
//
void SSIDchange()
{
  digitalWrite(led, 1);

  String ssidstr;
  String pswdstr;

  if (server.hasArg("ssid") && server.hasArg("pswd")) 
  {
    ssidstr = server.arg("ssid");
    pswdstr = server.arg("pswd");
    int t1=ssidstr.length();
    int t2=pswdstr.length();

    String content = "<html><body><meta http-equiv=\"refresh\" content=\"0; URL='http://";
    content += WiFi.localIP().toString();
    content += "'\" /></body></html>";
    server.send(200, "text/html", content); 
              
    if ((t1 > 4) && (t2 > 7)) 
    {
        DEBUG_PORT.println("Resetting..");
        WiFi.persistent(false);
        WiFi.disconnect(true,true);
        delay(500);
        WiFi.mode(WIFI_OFF);
        delay(500);
        //station set up as station
        WiFi.mode(WIFI_STA);
        DEBUG_PORT.print("Connecting to..."); // use a LAN if there is one..

        strcpy(ssid, ssidstr.c_str());
        trim(ssid);
        strcpy(password, pswdstr.c_str());
        trim(password);

        DEBUG_PORT.print("[");
        DEBUG_PORT.print(ssid);        
        DEBUG_PORT.print("]-[");
        DEBUG_PORT.print(password);
        DEBUG_PORT.println("]");
        saveSettings();       // store setting in EEPROM for reboot..

        WiFi.begin(ssid, password);

        // Wait for connection
        int timeout = 0;  
        while (WiFi.status() != WL_CONNECTED) 
        {
          delay(500);
          DEBUG_PORT.print(".");    
          if(timeout++ > 10)
          {
              DEBUG_PORT.println("No LAN.. or wrong login");
              ESP.restart();      // avoid hopelessness and start over..
          }          
        }

        DEBUG_PORT.print("Connected to LAN: ");
        DEBUG_PORT.println(WiFi.SSID());
        DEBUG_PORT.print("New IP address: ");
        DEBUG_PORT.println(WiFi.localIP());

        // HOST_PORT.print("IP:");             // Notify host
        // HOST_PORT.println(WiFi.localIP());
        sprintf(myIPstr,"%s",WiFi.localIP().toString().c_str());
        return;
    }
    
    if(t2 < 8)
      DEBUG_PORT.print("Password too short - ");
    
    if(t1 < 4)
      DEBUG_PORT.print("SSID too short - ");

    DEBUG_PORT.println("Log in Failed");
  }

  server.send(200, "text/html", SSIDformhtml);
}


//
// 404 handler for url requests that go nowhere..
//
void handleNotFound() {
  digitalWrite(led, 1);
  String message = "404 Site Not Found\n\n";
  message += "URI: ";
  message += server.uri();
  message += "\nMethod: ";
  message += (server.method() == HTTP_GET) ? "GET" : "POST";
  message += "\nArguments: ";
  message += server.args();
  message += "\n";

  for (uint8_t i = 0; i < server.args(); i++) {
    message += " " + server.argName(i) + ": " + server.arg(i) + "\n";
  }

  server.send(404, "text/plain", message);
  digitalWrite(led, 0);
}
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
void loop(void) {

  server.handleClient();

  if (interruptCounter > 0) {
 
    portENTER_CRITICAL(&timerMux);
    interruptCounter--;
    portEXIT_CRITICAL(&timerMux);
 
    totalInterruptCounter++;
 
    switchStatus = digitalRead(input1);       // read front panel switch state
    switchStatus<<=1;
    switchStatus |= digitalRead(input2);
    switchStatus<<=1;
    switchStatus |= digitalRead(input3);
    switchStatus<<=1;
    switchStatus |= digitalRead(input4);
    switchStatus<<=1;
    switchStatus |= digitalRead(input5);

    if (lastSwitchStatus != switchStatus)
    {
      handleRoot();                           // if front panel changes update page...
      lastSwitchStatus = switchStatus;

      digitalWrite(output1, digitalRead(input1));  // then set outputs to front panel setting..
      digitalWrite(output2, digitalRead(input2));
      digitalWrite(output3, digitalRead(input3));
      digitalWrite(output4, digitalRead(input4));
      digitalWrite(output5, digitalRead(input5));      

      DEBUG_PORT.print("Panel Change - ");
      DEBUG_PORT.println(switchStatus);
    }

    read_Radio();   // check for comms from radio to see if a band change has happened
  }
 
}

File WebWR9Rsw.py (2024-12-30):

import ctypes
import webview

def setup():
    # Create the window with specific dimensions
    webview.create_window('WR9R Ant Selector', 'http://192.168.1.179', width=300, height=450)

if __name__ == '__main__':
    # Minimize the console window
    ctypes.windll.user32.ShowWindow(ctypes.windll.kernel32.GetConsoleWindow(), 6)
    
    # Call the setup function before starting
    setup()
    webview.start()

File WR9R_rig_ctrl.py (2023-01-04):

#
# WR9R Auto Band Switch Manager
# This will automatically select the antenna based on band selected
# on the K3
# 01-01-2023   Larry D O'Cull    WR9R
#

import serial
import requests
import time
import tkinter as tk
import tkinter.font as tkFont
import winsound


MY_VERSION = "WR9R  V0.311w"
MY_SWITCH_URL = "http://192.168.1.179/"
MY_K3_COMM_PORT = "COM4"
MY_KAT500_COMM_PORT = "COM13"
MY_COMM_RATE = "38400"
MY_AUTOTUNE_ENABLE = "Y"    # Y = Enabled

## This is the WR9R K3-KAT500-WifiRemote Switching Antenna operating situation

band_LUT = [
# K3_string, switch_pos, tune_secs, KAT500_string
    [b'BN00',   "FIVE",    0,  b'AN3;MDB;', "160M"],    #160M   Dummy load for safety
    [b'BN01',   "THREE",   4,  b'AN2;MDM;T;',"80M"],  # 80M   Dipole
    [b'BN02',   "THREE",   3,  b'AN1;MDB;',  "60M"],    # 60M   Vertical
    [b'BN03',   "THREE",   3,  b'AN1;MDB;',  "40M"],    # 40M   Vertical
    [b'BN04',   "ONE",     4,  b'AN1;MDM;',  "30M"],    # 30M   Vertical
    [b'BN05',   "TWO",     1,  b'AN2;MDM;',  "20M"],    # 20M   HexBeam
    [b'BN06',   "TWO",     1,  b'AN2;MDM;',  "17M"],    # 17M   HexBeam
    [b'BN07',   "TWO",     1,  b'AN2;MDM;',  "15M"],    # 15M   HexBeam
    [b'BN08',   "TWO",     1,  b'AN2;MDM;',  "12M"],    # 12M   HexBeam
    [b'BN09',   "TWO",     1,  b'AN2;MDM;',  "10M"],    # 10M   HexBeam
    [b'BN10',   "TWO",     1,  b'AN2;MDM;',  "6M"]     #  6M   HexBeam
]
# other possibilities..
#    [b'BN01',   "THREE",   8,  b'AN2;MDM;T;'],  # 75M   Dipole tough-tune for 75M
#    [b'BN01',   "THREE",   4,  b'AN1;MDB;'],    # 80M   Vertical
#    [b'BN02',   "THREE",   5,  b'AN2;MDM;T;'],  # 60M   Dipole
#    [b'BN05',   "TWO",     3,  b'AN1;MDB;'],    # 20M   Vertical


tunerConfig = b''
last_data = b''
bandName = ""

#  the main window
window = tk.Tk()
window.geometry("300x200")
window.title(MY_VERSION)

#  a variable to store the checkbox value and set the default value
full_auto = tk.IntVar(value=1)
#  the checkbox
full_auto_checkbox = tk.Checkbutton(window, text="FullAuto", variable=full_auto)
full_auto_checkbox.pack(side="top")

#  a frame to hold the checkbox and caption
frame = tk.Frame(window)
frame.pack()
#  a label to display the caption and pack it into the frame
caption_font = tkFont.Font(size=20, weight="bold")
caption_label = tk.Label(frame, text="", font=caption_font)
caption_label.pack(side="top")

# Match the K3 string to the desired band from the LUT
def get_band_select(string):
    global bandName
    
    for i in range(len(band_LUT)):
        for j in range(len(band_LUT[i])):
            if band_LUT[i][j] == string:
                # Return the value at the next column
                bandName = band_LUT[i][j+4]
                return band_LUT[i][j+1]
    # Return None if the string is not found
    return None

# Match the K3 string to a tune-request per the LUT
def get_tune_request(string):
    global bandName
    global tunerConfig
        
    for i in range(len(band_LUT)):
        for j in range(len(band_LUT[i])):
            if band_LUT[i][j] == string:
                # Return the value at the next column
                tunerConfig = band_LUT[i][j+3]
                bandName = band_LUT[i][j+4]

                KAT500ser.write(tunerConfig) # set desired configuration on KAT500

                if (tunerConfig[2] == ord('1')):
                    option1.select()
                if (tunerConfig[2] == ord('2')):  # set radio button to reflect
                    option2.select()                # button change will update KAT500
                if (tunerConfig[2] == ord('3')):
                    option3.select()                    
                return band_LUT[i][j+2]
    # Return None if the string is not found
    return None

# Apply low-power TUNE signal to allow antenna tuners to adjust
def tune_default(secs):
    print("Tuning...")
    time.sleep(1)            
    K3ser.write(b"SWH16;")
    time.sleep(secs)            
    K3ser.write(b"SWH16;")
    print("Complete")

def band_poll_K3():
    time.sleep(0.25)
    K3ser.flushInput()
    K3ser.write(b"BN;")   # request band currently selected
    time.sleep(0.25)

def freq_poll_K3():
    time.sleep(0.25)
    K3ser.flushInput()
    K3ser.write(b"FA;")   # request the current dial frequency
    time.sleep(0.25)

# function to open the popup window
def tune_popup(secs):
    # warning sound...
    winsound.Beep(440, 500)
    #  the popup window
    popup = tk.Toplevel()
    popup.title("ALERT")
    popup.geometry("100x50")

    # function to be called when the "TUNE!" button is clicked
    def tune():
        print("Tuning up for %d.." % secs)
        time.sleep(1)            
        K3ser.write(b"SWH16;")
        time.sleep(secs)            
        K3ser.write(b"SWH16;")
        print("Complete")
        popup.destroy()    
    
    # "TUNE!" button
    tune_button = tk.Button(popup, text="TUNE!", command=tune)
    tune_button.pack(side="left")

    # "Exit" button
    exit_button = tk.Button(popup, text="Exit", command=popup.destroy)
    exit_button.pack(side="right")

# Set the WR9R Wifi-Enabled-Switch using HTTP_GET
def setWR9Rswitch(reply, data):
    global url

    if reply != None:
        response = requests.get(url + reply)
    else:
        print("No Change") # botched string handling

    if response == 0:
        print("+")
        
    elif response.status_code == 200:
        print("Success!")

        if (reply == "ONE"):    # set radio buttons accordingly
            switch1.select()
        if (reply == "TWO"):    # set radio buttons accordingly
            switch2.select()
        if (reply == "THREE"):    # set radio buttons accordingly
            switch3.select()
        if (reply == "FOUR"):    # set radio buttons accordingly
            switch4.select()
        if (reply == "FIVE"):    # set radio buttons accordingly
            switch5.select()

        if(data != 0):
            # Now issue a 'Tune' to set auto-antenna tuning
            tuningTime = get_tune_request(data)  # get desired settings
            if MY_AUTOTUNE_ENABLE == "Y" and tuningTime != 0:
                if full_auto.get() == 1:
                    tune_default(tuningTime)
                else:
                    tune_popup(tuningTime)

    elif response.status_code == 404:
        print("Resource not found!")
    else:
        print("Error!")

def setWR9R(data):
    reply = get_band_select(data)
    setWR9Rswitch(reply, data)

def switch_change():
    if (selected_switch.get() == "Pos 1"):
        setWR9Rswitch("ONE", 0)
    if (selected_switch.get() == "Pos 2"):
        setWR9Rswitch("TWO", 0)
    if (selected_switch.get() == "Pos 3"):
        setWR9Rswitch("THREE", 0)
    if (selected_switch.get() == "Pos 4"):
        setWR9Rswitch("FOUR", 0)
    if (selected_switch.get() == "Pos 5"):
        setWR9Rswitch("FIVE", 0)
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

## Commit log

2020-08-21 Firmware Source
    This is an Arduino-based solution developed in MSCode and PlatformIO
2020-08-21 Hardware Source
    These files contain schematic and PCB artwork developed in KiCAD
    [Switch.sch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]
2020-08-21 Update README.md
    This PCBA and Firmware provides a method to remotely control antenna selection within a LAN using a standard browser.
2022-12-28 Python Script for Automation
    This Python Script is for shack automation. The script polls my K3 every 2 seconds and looks for band changes. If the band changes, the WR9R Antenna Switch setting is retrieved from the lookup table 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
2022-12-29 WR9R Auto Band Switch Manager
    This will automatically select the antenna based on band selected
    on the K3. Updates allow better control of when tuning of an external
    ATU will be enabled (small signal output) and for how long.
2022-12-31 WR9R Auto Band Switch Manager
    Improved startup for cases such as no logging or other software running.
    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
2022-12-31 WR9R Auto Band Switch Manager
    (A little more code cleanup) ..This will automatically select the antenna based on band selected
    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
2023-01-01 WR9R Auto Band Switch Manager
    Cleanup and improved robustness. Also added KAT500 support to fully automate the band switch from radio through internal/external tuner to antenna.
2023-01-01 Station Automation Python Script
    This script runs in background monitoring band changes and setting the appropriate Wifi-Enabled-Selector output as well as configuring and tuning the Elecraft KAT500 and/or applying a 'tune' signal t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
2023-01-04 WR9R Station Control - Automatic Switching and Tuning (Python3)
    Script monitors the band switching and sets KAT500 and WR9R-Wifi-Selector according to selected band. Small UI allows for remote operations with VNC or another remote desktop tool.
2024-12-30 Web Switch Monitor
    This Python examples provides a remote control panel
2025-04-21 Upgrade to allow direct monitor of Elecraft K3
    This upgrade allows for the switch to instantly follow the rig.
    The return messages are monitored via RS232 and the switch follows the settings on the FREQS page.
    Frequency bands are defined in whole MHZ, comma separated, and a semicolon at the end of each line.
